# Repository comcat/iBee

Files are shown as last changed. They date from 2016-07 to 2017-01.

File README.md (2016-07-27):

iBee PCB Quadcopter
========================

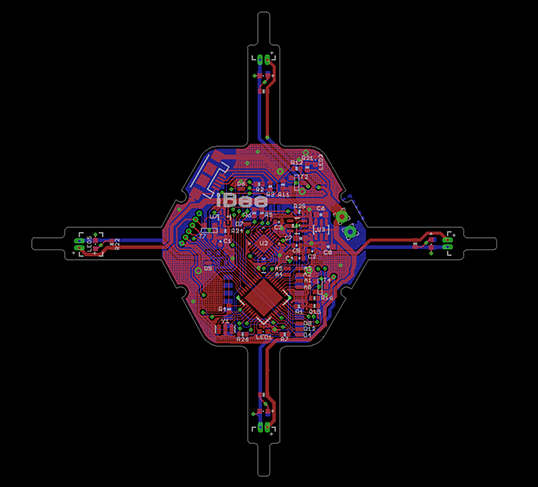
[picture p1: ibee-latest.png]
iBee Board V0.8


[*iBee Quadcopter Board PCB Layout (iBee V0.8)*](https://www.jackslab.org/)

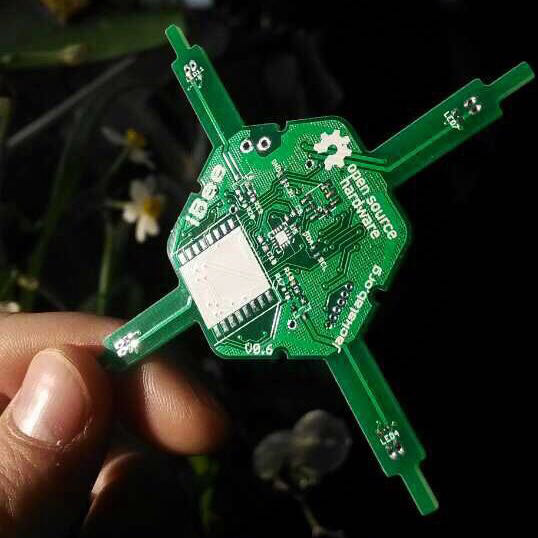
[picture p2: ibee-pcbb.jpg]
iBee PCB


[*iBee Quadcopter Board PCB (iBee V0.8)*](https://www.jackslab.org/)

It's based on the control board of Flexbot Quadcopter.

Repository Contents
-------------------
* hardware/V0.8/ - All Eagle design files (.brd, .sch) and Gerber files of iBee version 0.8

License Information
-------------------
The hardware is released under [Creative Commons ShareAlike 4.0 International](https://creativecommons.org/licenses/by-sa/4.0/).

Distributed as-is; no warranty is given.

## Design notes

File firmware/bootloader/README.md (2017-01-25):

iBee ATMega32u4 bootload
==========================

### Upload Tools

Using a FT232RL USB to UART board

### Connections

* 32U4_MISO -> FT232_CTS (Green)
* 32U4_SCK -> FT232_DSR  (Yellow)
* 32U4_MOSI -> FT232_DCD (Blue)
* 32U4_RESET -> FT232_RI (Orange)

### Build avrdude-serjtag

```bash
$ git clone git://github.com/laclefyoshi/avrdude-serjtag.git avrdude
$ cd avrdude
$ tar zxvf bin/avrdude-5.11.1.tar.gz
$ cd avrdude-5.11.1
$ (linux optional) patch -p1 < ../src/avrdude-5.8-baud.patch
$ patch -p1 < ../src/avrdude-5.10-serjtag.patch
$ patch -p1 < ../src/avrdude-5.11-serjtag.patch
$ patch -p1 < ../src/avrdude-5.8-ft245r.patch
$ patch -p1 < ../src/avrdude-5.11-ft245r.patch
$ patch -p1 < ../src/avrdude-5.8-confu2.patch
```

Installing libftd2xx drivers: http://www.ftdichip.com/Drivers/D2XX.htm

```bash
$ sudo apt-get install libusb-1.0.0-dev libusb-dev
$ ./configure CFLAGS="-g -O2 -DSUPPORT_FT245R" LIBS="-lftd2xx" --prefix=/usr/local
$ make
$ sudo make install
```

### Flash bootloader

```bash
$ make flash
```

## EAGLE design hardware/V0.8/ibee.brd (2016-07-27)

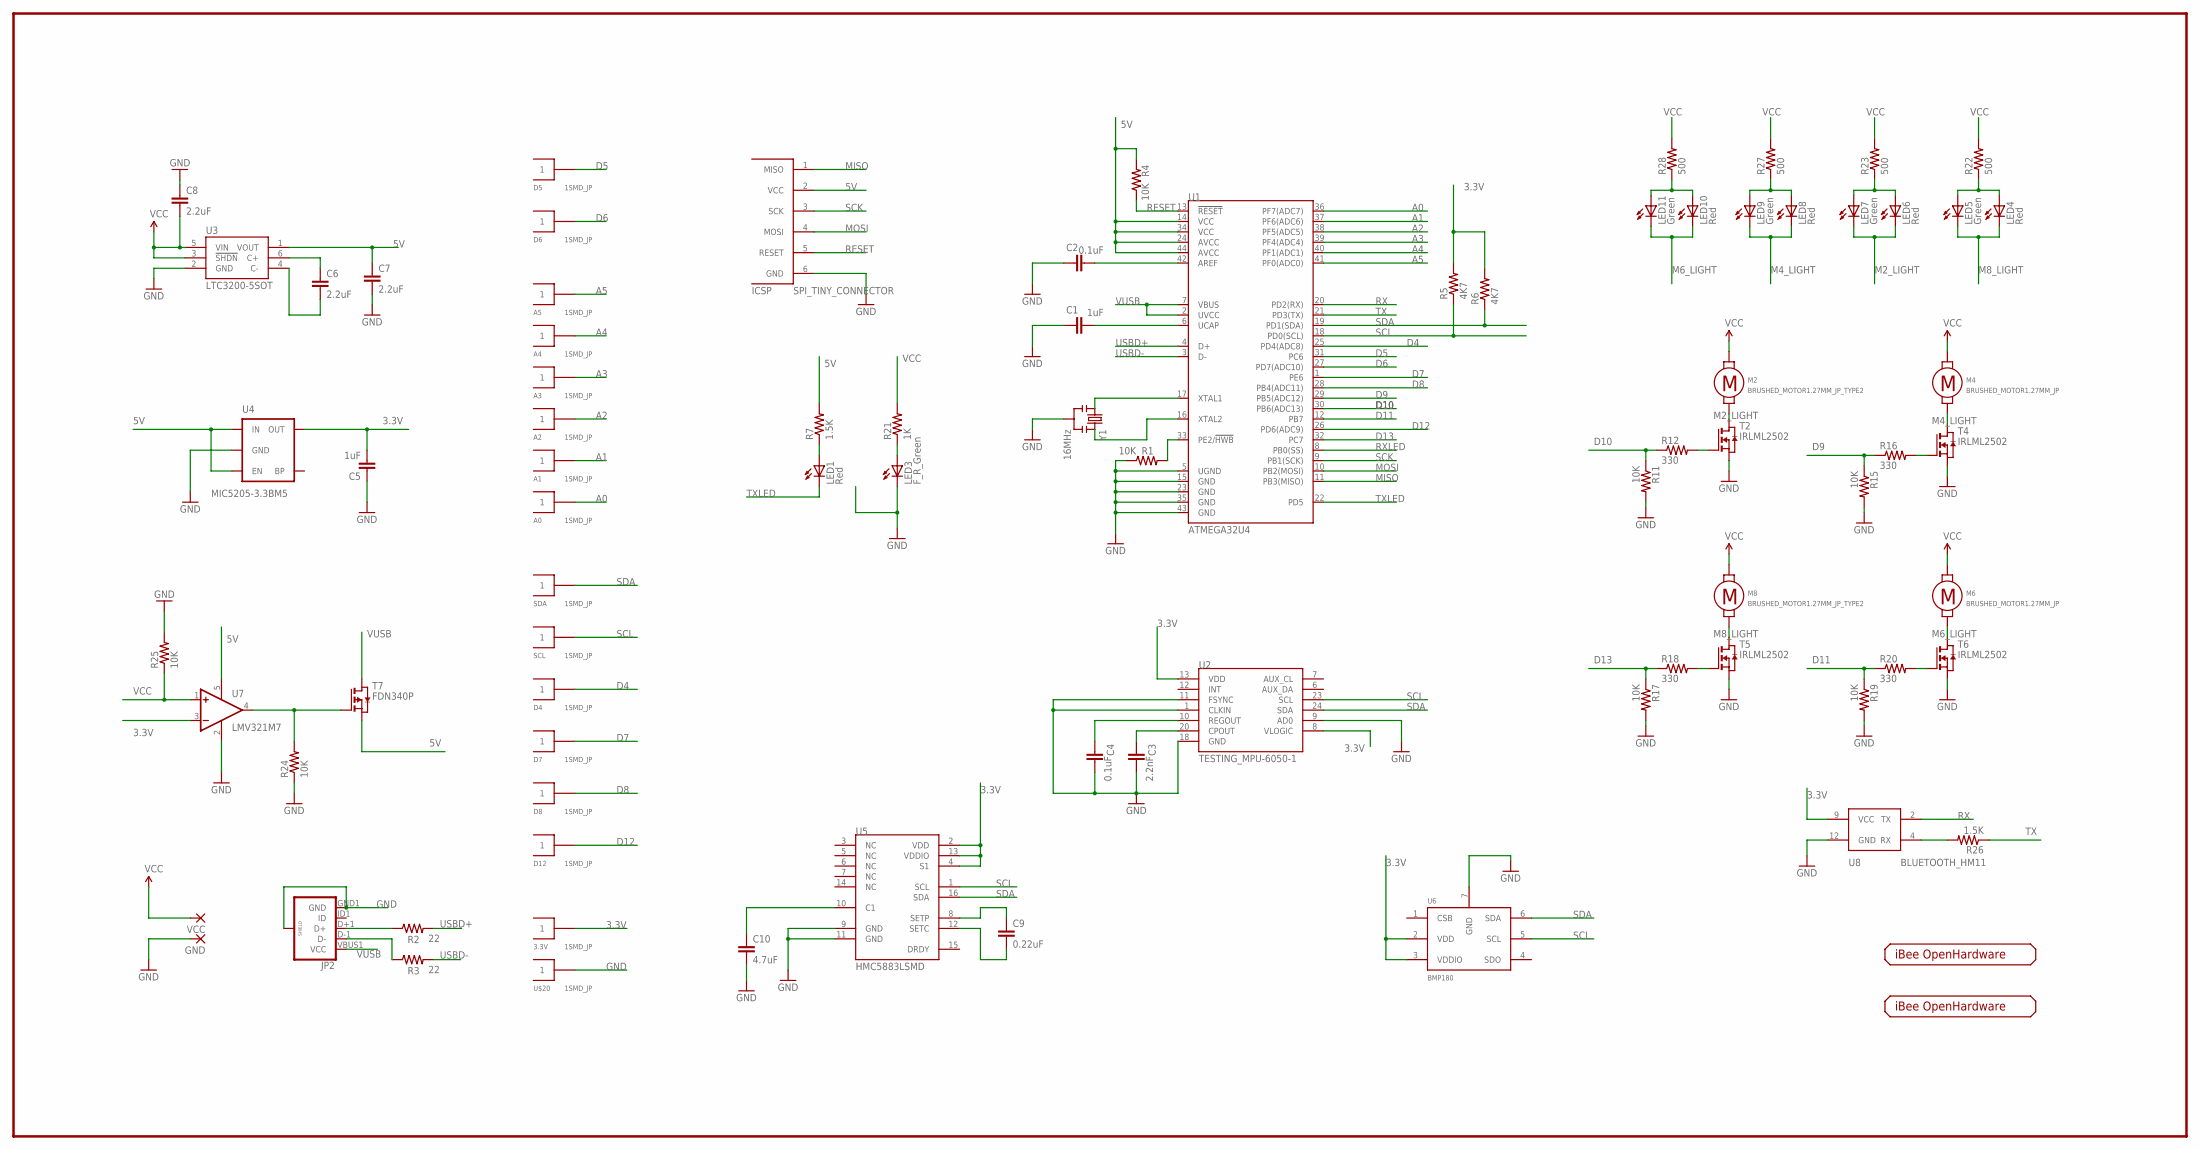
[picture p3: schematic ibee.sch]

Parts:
3.3V: 1SMD_JP; 1SMD
A0, A1, A2, A3, A4, A5: 1SMD_JP; 1SMD
C1, C5: 1uF; 0402-CAP
C2, C4: 0.1uF; 0402-CAP
C3: 2.2nF; 0402-CAP
C6, C7, C8: 2.2uF; 0603-CAP
C9: 0.22uF; 0402-CAP
C10: 4.7uF; 0603-CAP
D4, D5, D6, D7, D8, D12: 1SMD_JP; 1SMD
GND: 2,15/1,0
ICSP: SPI_TINY_CONNECTOR; AVR_ISP_TINY_CONNECTOR_NO_BORDER
JP2: USB_MICROB_PLUGCONN-11752; USB-B-MICRO-SMD_V03
LED1, LED4, LED6, LED8, LED10: Red; CHIPLED_0603
LED3: F_R_Green; CHIPLED_0603
LED5, LED7, LED9, LED11: Green; CHIPLED_0603
M2, M8: BRUSHED_MOTOR1.27MM_JP_TYPE2; BRUSHED_MOTOR_1.27MM_JP_TYPE2
M4, M6: BRUSHED_MOTOR1.27MM_JP; BRUSHED_MOTOR_1.27MM_JP
R1, R4, R11, R15, R17, R19, R24, R25: 10K; 0402-RES
R2, R3: 22; 0402-RES
R5, R6: 4K7; 0402-RES
R7, R26: 1.5K; 0402-RES
R12, R16, R18, R20: 330; 0402-RES
R21: 1K; 0402-RES
R22, R23, R27, R28: 500; 0402-RES
SCL: 1SMD_JP; 1SMD
SDA: 1SMD_JP; 1SMD
T2, T4, T5, T6: IRLML2502; SOT-23
T7: FDN340P; SOT23
U1: ATMEGA32U4; TESTING_QFN-44-7X7
U2: TESTING_MPU-6050-1; TESTING_QFN-24-4MM2
U3: LTC3200-5SOT; SOT23-6
U4: MIC5205-3.3BM5; SOT23-5
U5: HMC5883LSMD; TESTING_16LPCC
U6: BMP180
U7: LMV321M7; SC70-5L
U8: BLUETOOTH_HM11
U$1: IBEE-LOGO-T; IBEE-LOGO-TOP
U$2: IBEE-LOGO-B; FLEXBOT_LOGO_TYPE2
U$20: 1SMD_JP; 1SMD
VCC: 2,15/1,0
Y1: 16MHz; RESONATOR-SMD

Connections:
3.3V: 3.3V.1, C5.2, R5.2, R6.2, U2.8 (VLOGIC), U2.13 (VDD), U4.5 (OUT), U5.2 (VDD), U5.4 (S1), U5.13 (VDDIO), U6.2 (VDD), U6.3 (VDDIO), U7.3 (-IN), U8.9 (VCC)
5V: C7.1, ICSP.2 (VCC), R4.2, R7.2, T7.2 (S), U1.14 (VCC), U1.24 (AVCC), U1.34 (VCC), U1.44 (AVCC), U3.1 (VOUT), U4.1 (IN), U4.3 (EN), U7.5 (V+)
A0: A0.1, U1.36 (PF7(ADC7))
A1: A1.1, U1.37 (PF6(ADC6))
A2: A2.1, U1.38 (PF5(ADC5))
A3: A3.1, U1.39 (PF4(ADC4))
A4: A4.1, U1.40 (PF1(ADC1))
A5: A5.1, U1.41 (PF0(ADC0))
D4: D4.1, U1.25 (PD4(ADC8))
D5: D5.1, U1.31 (PC6)
D6: D6.1, U1.27 (PD7(ADC10))
D7: D7.1, U1.1 (PE6)
D8: D8.1, U1.28 (PB4(ADC11))
D9: R15.1, R16.1, U1.29 (PB5(ADC12))
D10: R11.1, R12.1, U1.30 (PB6(ADC13))
D11: R19.1, R20.1, U1.12 (PB7)
D12: D12.1, U1.26 (PD6(ADC9))
D13: R17.1, R18.1, U1.32 (PC7)
GND: C1.1, C2.1, C3.2, C4.2, C5.1, C7.2, C8.1, C10.2, GND.1, ICSP.6 (GND), JP2.GND1 (GND), JP2.SHIELD1 (SHIELD), JP2.SHIELD2 (SHIELD), JP2.SHIELD3 (SHIELD), LED3.C, R1.1, R11.2, R15.2, R17.2, R19.2, R24.1, R25.2, T2.2 (S), T4.2 (S), T5.2 (S), T6.2 (S), U1.5 (UGND), U1.15 (GND), U1.23 (GND), U1.35 (GND), U1.43 (GND), U2.1 (CLKIN), U2.9 (AD0), U2.11 (FSYNC), U2.18 (GND), U3.2 (GND), U4.2 (GND), U5.9 (GND), U5.11 (GND), U6.7 (GND), U7.2 (V-), U8.12 (GND), U$20.1, Y1.2
M2_LIGHT: LED6.C, LED7.C, M2.P$1 (1), T2.1 (D)
M4_LIGHT: LED8.C, LED9.C, M4.P$1 (1), T4.1 (D)
M6_LIGHT: LED10.C, LED11.C, M6.P$1 (1), T6.1 (D)
M8_LIGHT: LED4.C, LED5.C, M8.P$1 (1), T5.1 (D)
MISO: ICSP.1 (MISO), U1.11 (PB3(MISO))
MOSI: ICSP.4 (MOSI), U1.10 (PB2(MOSI))
unnamed: U1.17 (XTAL1), Y1.1
unnamed: U1.16 (XTAL2), Y1.3
unnamed: JP2.D+1 (D+), R2.1
unnamed: JP2.D-1 (D-), R3.1
unnamed: C1.2, U1.6 (UCAP)
unnamed: C2.2, U1.42 (AREF)
unnamed: C4.1, U2.10 (REGOUT)
unnamed: C3.1, U2.20 (CPOUT)
unnamed: LED1.A, R7.1
unnamed: R1.2, U1.33 (PE2/!HWB)
unnamed: R18.2, T5.3 (G)
unnamed: LED3.A, R21.1
unnamed: R12.2, T2.3 (G)
unnamed: LED8.A, LED9.A, R27.1
unnamed: R16.2, T4.3 (G)
unnamed: LED10.A, LED11.A, R28.1
unnamed: LED6.A, LED7.A, R23.1
unnamed: C9.1, U5.8 (SETP)
unnamed: LED4.A, LED5.A, R22.1
unnamed: C6.1, U3.6 (C+)
unnamed: C6.2, U3.4 (C-)
unnamed: C9.2, U5.12 (SETC)
unnamed: C10.1, U5.10 (C1)
unnamed: R20.2, T6.3 (G)
unnamed: R24.2, T7.3 (G), U7.4 (OUT)
unnamed: R26.2, U8.4 (RX)
RESET: ICSP.5 (RESET), R4.1, U1.13 (!RESET)
RX: U1.20 (PD2(RX)), U8.2 (TX)
RXLED: U1.8 (PB0(SS))
SCK: ICSP.3 (SCK), U1.9 (PB1(SCK))
SCL: R5.1, SCL.1, U1.18 (PD0(SCL)), U2.23 (SCL), U5.1 (SCL), U6.5 (SCL)
SDA: R6.1, SDA.1, U1.19 (PD1(SDA)), U2.24 (SDA), U5.16 (SDA), U6.6 (SDA)
TX: R26.1, U1.21 (PD3(TX))
TXLED: LED1.C, U1.22 (PD5)
USBD+: R2.2, U1.4 (D+)
USBD-: R3.2, U1.3 (D-)
VCC: C8.2, M2.P$2 (2), M4.P$2 (2), M6.P$2 (2), M8.P$2 (2), R21.2, R22.2, R23.2, R25.1, R27.2, R28.2, U3.3 (!SHDN), U3.5 (VIN), U7.1 (+IN), VCC.1
VUSB: JP2.VBUS1 (VCC), T7.1 (D), U1.2 (UVCC), U1.7 (VBUS)

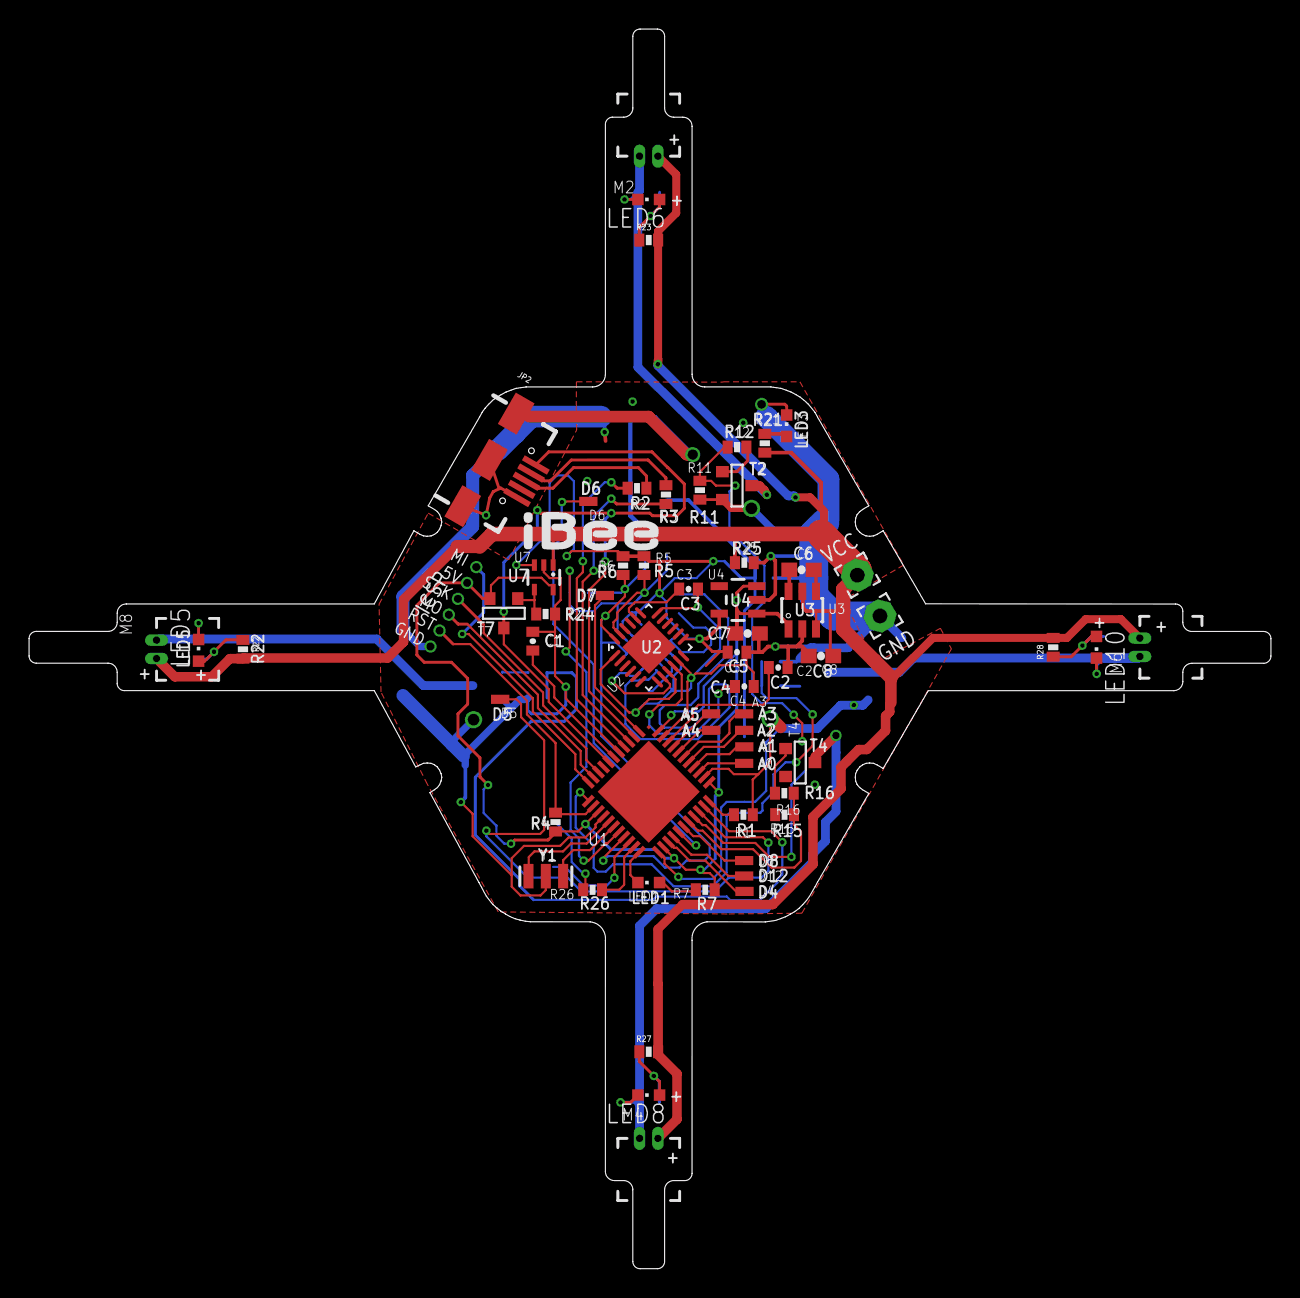
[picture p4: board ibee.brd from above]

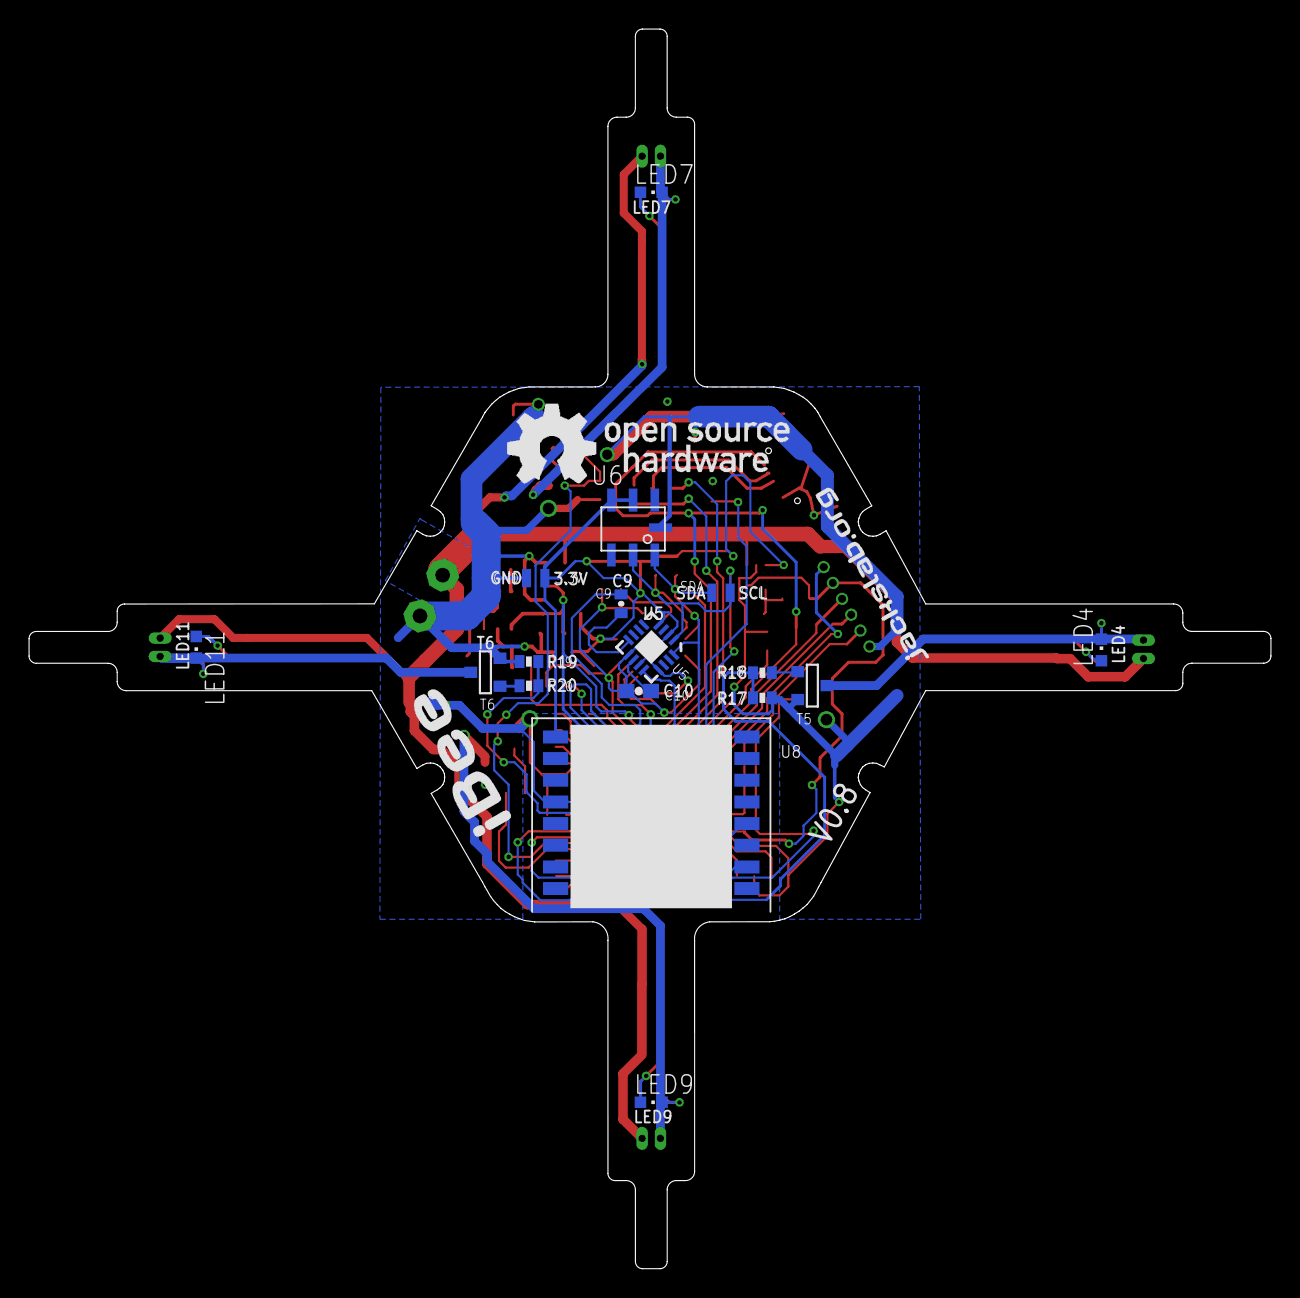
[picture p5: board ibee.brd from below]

Board: 2 copper layers, 86.0 x 85.8 mm, 83 parts (20 on the bottom side), 62 nets.

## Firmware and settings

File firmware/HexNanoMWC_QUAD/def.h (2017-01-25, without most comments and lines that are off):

#if COPTERTEST == 1
  #define QUADP
  #define WMP
#elif COPTERTEST == 2
  #define FLYING_WING
  #define WMP
  #define BMA020
  #define FAILSAFE
  #define LCD_CONF
  #define LCD_TEXTSTAR
  #define VBAT
  #define POWERMETER_SOFT
#elif COPTERTEST == 3
  #define TRI
  #define FREEIMUv035_MS
  #define BUZZER
  #define VBAT
  #define POWERMETER_HARD
  #define LCD_CONF
  #define LCD_CONF_AUX
  #define LCD_VT100
  #define LCD_TELEMETRY
  #define LCD_TELEMETRY_STEP "01245"
  #define LOG_VALUES 1
  #define SUPPRESS_BARO_ALTHOLD
  #define VARIOMETER 12
#elif COPTERTEST == 4
  #define QUADX
  #define CRIUS_SE
  #define SPEKTRUM 2048
  #define LED_RING
  #define GPS_SERIAL 2
  #define LOG_VALUES 2
  #define CYCLETIME_FIXATED 9000
  #define LOG_PERMANENT 1023
  #define LOG_PERMANENT_SERVICE_LIFETIME 36000
#elif COPTERTEST == 5
  #define HELI_120_CCPM
  #define CRIUS_LITE
  #undef DISABLE_POWER_PIN
  #define RCAUXPIN8
  #define OLED_I2C_128x64
  #define LCD_TELEMETRY
  #define LOG_VALUES 3
  #define DEBUG
  #undef SERVO_RFR_50HZ
  #define SERVO_RFR_160HZ
  #define VBAT
  #define POWERMETER_SOFT
  #define MMGYRO 10
  #define MMGYROVECTORLENGTH 15
  #define GYRO_SMOOTHING {45, 45, 50}
  #define INFLIGHT_ACC_CALIBRATION
  #define LOG_PERMANENT 1023
  #define LOG_PERMANENT_SHOW_AT_STARTUP
  #define LOG_PERMANENT_SHOW_AT_L
  #define LOG_PERMANENT_SERVICE_LIFETIME 36000
#elif defined(COPTERTEST)
  #error "*** this test is not yet defined"
#endif
#if defined(__AVR_ATmega168__) || defined(__AVR_ATmega328P__)
  #define PROMINI
#endif
#if defined(__AVR_ATmega32U4__) || defined(TEENSY20)
  #define PROMICRO
#endif
#if defined(__AVR_ATmega1280__) || defined(__AVR_ATmega1281__) || defined(__AVR_ATmega2560__) || defined(__AVR_ATmega2561__)
  #define MEGA
#endif
#if defined (AIRPLANE) || defined(FLYING_WING)|| defined(SINGLECOPTER)|| defined(DUALCOPTER)
  #define FIXEDWING
#endif
#if defined(HELI_120_CCPM) || defined(HELI_90_DEG)
  #define HELICOPTER
#endif
#if defined(BI) || defined(TRI) || defined(SERVO_TILT) || defined(GIMBAL) || defined(FLYING_WING) || defined(AIRPLANE) || defined(CAMTRIG) || defined(HELICOPTER) || defined(SERVO_MIX_TILT)|| defined(SINGLECOPTER)|| defined(DUALCOPTER)
  #define SERVO
#endif
#if defined(GIMBAL)
  #define NUMBER_MOTOR     0
  #define PRI_SERVO_FROM   1 // use servo from 1 to 2
  #define PRI_SERVO_TO     2
#elif defined(FLYING_WING)
  #define NUMBER_MOTOR     1
  #define PRI_SERVO_FROM   1 // use servo from 1 to 2
  #define PRI_SERVO_TO     2
#elif defined(SINGLECOPTER)
  #define NUMBER_MOTOR     1
  #define PRI_SERVO_FROM   4 // use servo from 4 to 7
  #define PRI_SERVO_TO     7
#elif defined(DUALCOPTER)
  #define NUMBER_MOTOR     2
  #define PRI_SERVO_FROM   4 // use servo from 5 to 6
  #define PRI_SERVO_TO     6
#elif defined(AIRPLANE)
    #if defined (USE_THROTTLESERVO)
      #define NUMBER_MOTOR     0
    #else
      #define NUMBER_MOTOR     1
    #endif
    #if defined(FLAPS)
      #define PRI_SERVO_FROM   3 // use servo from 3 to 8
      #undef CAMTRIG             // Disable Camtrig on A2
    #else
      #define PRI_SERVO_FROM   4 // use servo from 4 to 8
    #endif
  #define PRI_SERVO_TO     8
#elif defined(BI)
  #define NUMBER_MOTOR     2
  #define PRI_SERVO_FROM   5 // use servo from 5 to 6
  #define PRI_SERVO_TO     6
#elif defined(TRI)
  #define NUMBER_MOTOR     3
  #define PRI_SERVO_FROM   6 // use only servo 6
  #define PRI_SERVO_TO     6
#elif defined(QUADP) || defined(QUADX) || defined(Y4)|| defined(VTAIL4)
  #define NUMBER_MOTOR     4
#elif defined(Y6) || defined(HEX6) || defined(HEX6X) || defined(HEX6H)
  #define NUMBER_MOTOR     6
#elif defined(OCTOX8) || defined(OCTOFLATP) || defined(OCTOFLATX)
  #define NUMBER_MOTOR     8
#elif defined(HELICOPTER)
  #ifdef HELI_USE_SERVO_FOR_THROTTLE
    #define NUMBER_MOTOR     0 // use servo to drive throttle output
    #define PRI_SERVO_FROM   4 // use servo from 4 to 8
    #define PRI_SERVO_TO     8
  #else
    #define NUMBER_MOTOR     1 // use 1 motor for throttle
    #define PRI_SERVO_FROM   4 // use servo from 4 to 7
    #define PRI_SERVO_TO     7
  #endif
#endif
#if (defined(SERVO_TILT)|| defined(SERVO_MIX_TILT))&& defined(CAMTRIG)
  #define SEC_SERVO_FROM   1 // use servo from 1 to 3
  #define SEC_SERVO_TO     3
#else
  #if defined(SERVO_TILT)|| defined(SERVO_MIX_TILT)
    #if defined(A0_A1_PIN_HEX) && (NUMBER_MOTOR == 6) && defined(PROMINI)
      #define SEC_SERVO_FROM   3 // use servo from 3 to 4
      #define SEC_SERVO_TO     4
    #else
      #if !defined(MEGA_HW_PWM_SERVOS) // if HW Gimbal is active we dont need the SW PWM defines
        #define SEC_SERVO_FROM   1 // use servo from 1 to 2
        #define SEC_SERVO_TO     2
      #endif
    #endif
  #endif
  #if defined(CAMTRIG)
    #define SEC_SERVO_FROM   3 // use servo 3
    #define SEC_SERVO_TO     3
  #endif
#endif
#if defined(SIRIUS_AIR) || defined(SIRIUS_AIR_GPS)
  #define RCAUX2PIND17
#endif
#if defined(PROMINI)
  #if !defined(MONGOOSE1_0)
    #define LEDPIN_PINMODE             pinMode (13, OUTPUT);
    #define LEDPIN_TOGGLE              PINB |= 1<<5;     //switch LEDPIN state (digital PIN 13)
    #define LEDPIN_OFF                 PORTB &= ~(1<<5);
    #define LEDPIN_ON                  PORTB |= (1<<5);
  #endif
  #if !defined(RCAUXPIN8)
    #if !defined(MONGOOSE1_0)
      #define BUZZERPIN_PINMODE          pinMode (8, OUTPUT);
      #if NUMBER_MOTOR >4
        #undef PILOTLAMP
      #endif
      #if defined PILOTLAMP && NUMBER_MOTOR <5
        #define    PL_PIN_ON            PORTB |= 1;
        #define    PL_PIN_OFF           PORTB &= ~1;
      #else
        #define BUZZERPIN_ON            PORTB |= 1;
        #define BUZZERPIN_OFF           PORTB &= ~1;
      #endif
    #endif
  #else
    #define BUZZERPIN_PINMODE          ;
    #define BUZZERPIN_ON               ;
    #define BUZZERPIN_OFF              ;
    #define RCAUXPIN
  #endif
  #if !defined(RCAUXPIN12) && !defined(DISABLE_POWER_PIN)
    #define POWERPIN_PINMODE           pinMode (12, OUTPUT);
    #define POWERPIN_ON                PORTB |= 1<<4;
    #define POWERPIN_OFF               PORTB &= ~(1<<4); //switch OFF WMP, digital PIN 12
  #else
    #define POWERPIN_PINMODE           ;
    #define POWERPIN_ON                ;
    #define POWERPIN_OFF               ;
  #endif
  #if defined(RCAUXPIN12)
    #define RCAUXPIN
  #endif
  #define I2C_PULLUPS_ENABLE         PORTC |= 1<<4; PORTC |= 1<<5;   // PIN A4&A5 (SDA&SCL)
  #define I2C_PULLUPS_DISABLE        PORTC &= ~(1<<4); PORTC &= ~(1<<5);
  #if !defined(MONGOOSE1_0)
    #define PINMODE_LCD                pinMode(0, OUTPUT);
    #define LCDPIN_OFF                 PORTD &= ~1; //switch OFF digital PIN 0
    #define LCDPIN_ON                  PORTD |= 1;
    #define STABLEPIN_PINMODE          ;
    #define STABLEPIN_ON               ;
    #define STABLEPIN_OFF              ;
  #endif
  #define PPM_PIN_INTERRUPT          attachInterrupt(0, rxInt, RISING); //PIN 0
  #define SPEK_SERIAL_PORT           0
  #define THROTTLEPIN                2
  #define ROLLPIN                    4
  #define PITCHPIN                   5
  #define YAWPIN                     6
  #define AUX1PIN                    7
  #define AUX2PIN                    0 // optional PIN 8 or PIN 12
  #define AUX3PIN                    1 // unused
  #define AUX4PIN                    3 // unused
  #define PCINT_PIN_COUNT            5
  #define PCINT_RX_BITS              (1<<2),(1<<4),(1<<5),(1<<6),(1<<7)
  #define PCINT_RX_PORT              PORTD
  #define PCINT_RX_MASK              PCMSK2
  #define PCIR_PORT_BIT              (1<<2)
  #define RX_PC_INTERRUPT            PCINT2_vect
  #define RX_PCINT_PIN_PORT          PIND
  #define V_BATPIN                   A3    // Analog PIN 3
  #define PSENSORPIN                 A2    // Analog PIN 2
  #if defined(A0_A1_PIN_HEX) || (NUMBER_MOTOR > 6)
    #define SOFT_PWM_1_PIN_HIGH        PORTC |= 1<<0;
    #define SOFT_PWM_1_PIN_LOW         PORTC &= ~(1<<0);
    #define SOFT_PWM_2_PIN_HIGH        PORTC |= 1<<1;
    #define SOFT_PWM_2_PIN_LOW         PORTC &= ~(1<<1);
  #else
    #define SOFT_PWM_1_PIN_HIGH        PORTD |= 1<<5;
    #define SOFT_PWM_1_PIN_LOW         PORTD &= ~(1<<5);
    #define SOFT_PWM_2_PIN_HIGH        PORTD |= 1<<6;
    #define SOFT_PWM_2_PIN_LOW         PORTD &= ~(1<<6);
  #endif
  #define SOFT_PWM_3_PIN_HIGH        PORTC |= 1<<2;
  #define SOFT_PWM_3_PIN_LOW         PORTC &= ~(1<<2);
  #define SOFT_PWM_4_PIN_HIGH        PORTB |= 1<<4;
  #define SOFT_PWM_4_PIN_LOW         PORTB &= ~(1<<4);
  #define SERVO_1_PINMODE            pinMode(A0,OUTPUT); // TILT_PITCH - WING left
  #define SERVO_1_PIN_HIGH           PORTC |= 1<<0;
  #define SERVO_1_PIN_LOW            PORTC &= ~(1<<0);
  #define SERVO_2_PINMODE            pinMode(A1,OUTPUT); // TILT_ROLL  - WING right
  #define SERVO_2_PIN_HIGH           PORTC |= 1<<1;
  #define SERVO_2_PIN_LOW            PORTC &= ~(1<<1);
  #define SERVO_3_PINMODE            pinMode(A2,OUTPUT); // CAM TRIG  - alt TILT_PITCH
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

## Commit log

2016-07-27 add the design files of version 0.8
    [ibee.brd, ibee.sch]
2016-07-27 update readme and add a pcb image

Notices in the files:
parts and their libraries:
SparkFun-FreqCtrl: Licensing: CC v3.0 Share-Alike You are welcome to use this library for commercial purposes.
